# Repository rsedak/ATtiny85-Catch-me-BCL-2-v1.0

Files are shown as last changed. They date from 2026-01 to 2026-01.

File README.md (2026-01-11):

[Croatian version](README_HR-HR.md).

Introduction
============
My friend Zvonimir Lapov asked me if I could design THT PCB which would be used in primary school student education.
Purpose of 'Catch me BCL-2' module is student education. It shows advantages of charlieplexing with seven BI-color LEDs.
This version is designed for the case when the BI-color LED has a brighter LED on pin 3.
There are many variations of bi-color LEDs on the market, so you will need to define the resistors yourself.

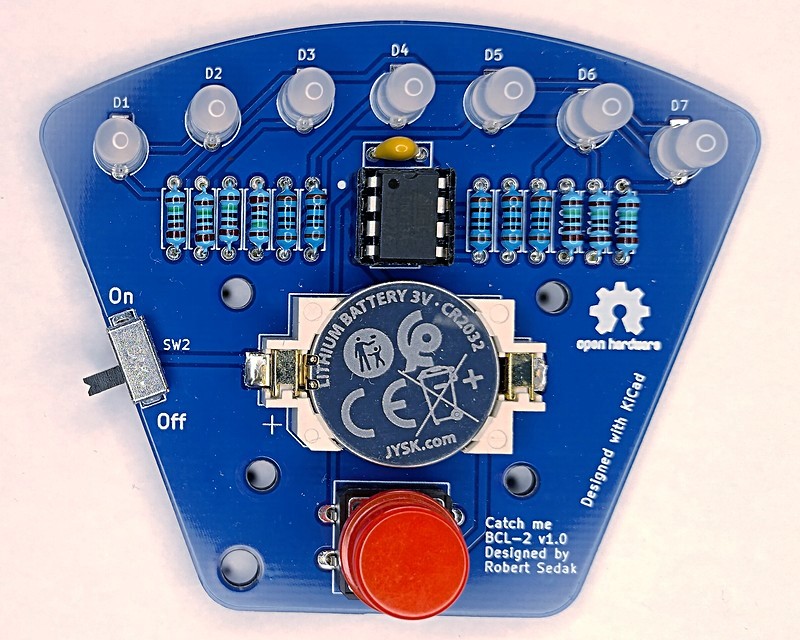
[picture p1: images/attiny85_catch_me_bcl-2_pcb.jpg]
PCB front Catch me BCL-2 educational module

Photo by Robert Sedak

Warning:
------------
In order for the program to be fully executed, the RESET pin on the ATtiny must be declared as an input/output pin. This is achieved by activating the FUSE bit called RSTDISBL. If we want to reprogram the ATtiny afterwards, we must turn off the FUSE bit called RSTDISBL using the high-voltage (12V) programming technique.
The procedure for programming the FUSE bits and the high-voltage programming technique can be found in professional literature. Use your newly acquired knowledge only when you fully understand what you have to do. Otherwise, you may damage the microcontroller.

Contributor
------------
- Robert Sedak — features, programming, schematic design, CAD design, case for PCB
- Zvonimir Lapov - idea

Application
-----------
Robert Sedak made a video with example programmed in Arduino IDE with ATtiny85 support:

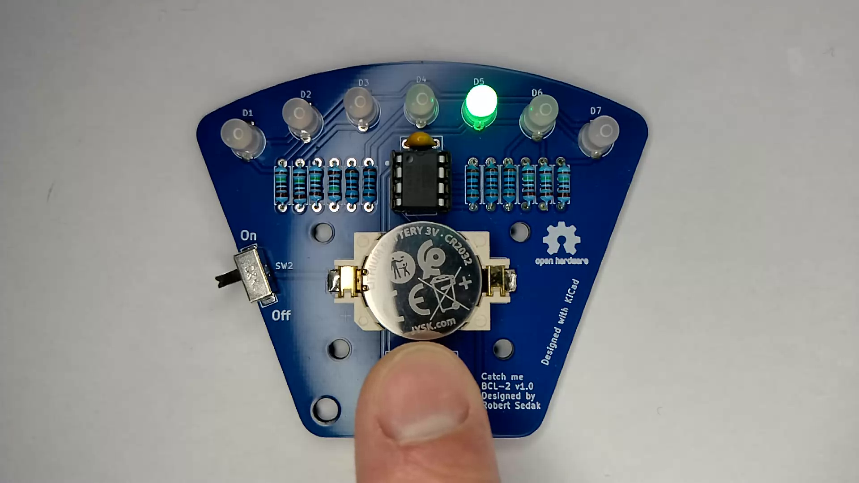
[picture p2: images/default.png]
PCB application (https://youtu.be/r-Ip-7PmgAQ "Catch me BCL-2 educational module example")

Photo by Robert Sedak

You can download example for Arduino IDE from [here](examples/).

Bill Of Materials
-----------------
- 1 ea., PCB
- 5 ea., 100 ohm 1/4W 1% Resistor (R1, R2, R3, R4, R5)
- 7 ea., 1.5K ohm 1/4W 1% Resistor (R6, R7, R8, R9, R10, R11, R12)
- 7 ea., BI-color LED 5mm (D1, D2, D3, D4, D5, D6, D7) with common cathode
- 4 ea., 6x6x4.3mm SPST Momentary push switch (SW1)
- 1 ea., SDPT 1P2T slide switch (SW2)
- 1 ea., 100nF 50V Monolithic Ceramic Capacitor
- 1 ea., 8-Pin DIL IC Socket
- 1 ea., ATtiny85 or ATtiny13A
- 1 ea., battery holder Keystone 1060
- 1 ea., battery 2032

Design Files
------------
This project is designed using Open Source [KiCad](http://kicad.org/). Design files are located in the [design_files](design_files/) folder.  You can see the [schematic](images/attiny85_catch_me_bcl-2_schematic.pdf).

Gerber files
------------
You can download gerber files from [here](gerber/attiny85_catch_me_bcl-2.zip).

Firmware
--------
This project can be programmed using the Open Source [Arduino](https://www.arduino.cc/).
[ATTinyCore by Spence Konde](https://github.com/SpenceKonde/ATTinyCore) was used to program ATtiny85 in Arduino IDE
[MicroCore by MCUdude](https://github.com/MCUdude/MicroCore) was used to program ATtiny13 in Arduino IDE.
Arduino examples for Arduino IDE are located in [examples](examples/) folder.

Case
-------
Robert Sedak created case for PCB. You can download STL and FCStd file from [case](case/) folder.
This case was designed using Open Spource [FreeCAD](https://www.freecad.org/).

**Bill Of Connecting Materials**
- 4 ea., M3 nuts
- 4 ea., M3x5mm + 4mm  Male to Female plastic Hex Spacer
- 4 ea., M3x5mm plastic screw

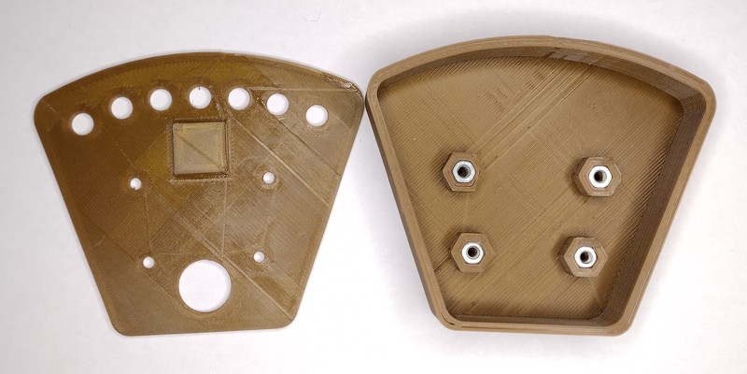
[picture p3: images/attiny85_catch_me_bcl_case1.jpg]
Shield case Catch me educational module

Photo by Robert Sedak

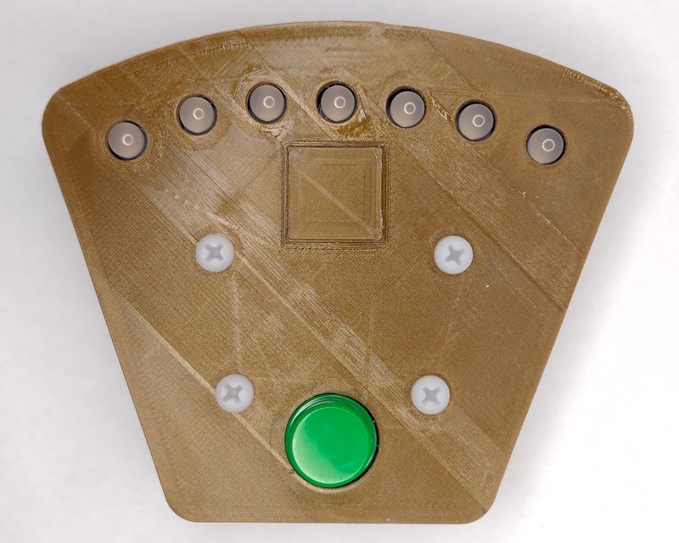
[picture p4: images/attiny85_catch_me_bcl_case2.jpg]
Shield case Catch me educational module

Photo by Robert Sedak

License
-------
[Attribution-ShareAlike 4.0 International (CC BY-SA 4.0)](https://creativecommons.org/licenses/by-sa/4.0/)

You are free to:
- Share — copy and redistribute the material in any medium or format
- Adapt — remix, transform, and build upon the material

This license is acceptable for Free Cultural Works.
- The licensor cannot revoke these freedoms as long as you follow the license terms.

Under the following terms:
- Attribution — You must give appropriate credit, provide a link to the license, and indicate if changes were made. You may do so in any reasonable manner, but not in any way that suggests the licensor endorses you or your use.
- ShareAlike — If you remix, transform, or build upon the material, you must distribute your contributions under the same license as the original.

No additional restrictions — You may not apply legal terms or technological measures that legally restrict others from doing anything the license permits.

Reference Designs ARE PROVIDED "AS IS" AND "WITH ALL FAULTS". Authors DISCLAIMS ALL OTHER WARRANTIES, EXPRESS OR IMPLIED, REGARDING PRODUCTS, INCLUDING BUT NOT LIMITED TO, ANY IMPLIED WARRANTIES OF MERCHANTABILITY OR FITNESS FOR A PARTICULAR PURPOSE.
Authors may make changes to specifications and product descriptions at any time, without notice. The Customer must notrely on the absence or characteristics of any features or instructions marked "reserved" or "undefined."
Authors reservesthese for future definition and shall have no responsibility whatsoever for conflicts or incompatibilities arising from future changes to them. The product information on the Web Site or Materials is subject to change without notice. Do not finalize a design with this info.

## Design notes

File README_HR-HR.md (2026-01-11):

[Engleska verzija](README.md).

Uvod
============
Prijatelj Zvonimir Lapov me upitao bi li mogao dizajnirati pločicu u THT tehnologiji za potrebe edukacije učenika osnovnih škola.
Svrha edukacijskog modula "Uhvati me BCL-2" je edukacija učenika. Pokazuje prednosti spajanja sedam dvobojnih svjetlećih dioda u spoj charlieplexing (multipleksiranje sa tri stanja).
Ova verzija je dizajnirana za slučaj kada dvobojna svjetleću dioda ima svjetliju diodu na pinu 3.
Na tržištu postoji mnogo varijacija dvobojnih svjetlećih dioda, pa ćete morati sami definirati otpornike.

PCB application Edukacijski modul Uhvati me BCL-2
Fotografirao Robert Sedak

Pozor:
------------
Kako bi se program u cijelosti mogao izvršiti, na ATtiny pin RESET moramo deklarirati kao ulazno/izlazni pin. To se postiže aktiviranjem FUSE bita s nazivom RSTDISBL. Ukoliko nakon toga želimo ponovno programirati ATtiny, moramo isključiti FUSE bit s nazivom RSTDISBL pomoću tehnike programiranja pomoću visokog napona (12V).
Postupak programiranja FUSE bitova i tehniku programiranja pomoću visokog napona potražite u stručnoj literaturi. Novostećena znanja koristite tek kada potpuno razumijete što morate napraviti. U suprotnom možete oštetiti mikroupravljač.

Autor
------------
- Robert Sedak — svojstva, programiranje, dizajn el. scheme, CAD dizajn, kučište
- Zvonimir Lapov - ideja

Programiranje
-----------
Robert Sedak je snimio video s primjerom programiranim u Arduino IDE s podrškom za ATtiny85:
PCB application (https://youtu.be/r-Ip-7PmgAQ "Edukacijski modul Uhvati me BCL-2 - primjer programiranja")
Fotografirao Robert Sedak

Primjere za Arduino IDE možete preuzeti [ovdje](examples/).

Popis komponenti
-----------------
- 1 kom, PCB
- 5 kom, 100 ohm 1/4W 1% otpornik (R1, R2, R3, R4, R5)
- 7 kom, 1.5K ohm 1/4W 1% otpornik (R6, R7, R8, R9, R10, R11, R12)
- 7 kom, dvobojna LED 5mm (D1, D2, D3, D4, D5, D6, D7) za zajedničkom katodom
- 1 kom, 6x6x4.3mm SPST tipkalo (SW1)
- 1 kom, SDPT 1P2T pomični prekidač (SW2)
- 1 kom, 100nF 50V keramički kondenzator
- 1 kom, 8-Pin DIL IC podnožje
- 1 kom, ATtiny85 ili ATtiny13A
- 1 kom, kučište za bateriju Keystone 1060
- 1 kom, baterija 2032

Datoteke s dizajnom
------------
Ovaj semafor je dizajniran pomoću programa [KiCad](http://kicad.org/). Datoteke se nalaze u mapi [design_files](design_files/). Elekroničku schemu možete pogledati [ovdje](images/attiny85_catch_me_bcl-2_schematic.pdf).

Gerber datoteke
------------
Gerber datoteke možete preuzeti [ovdje](gerber/attiny85_catch_me_bcl-2.zip).

Firmware
--------
Ovo učilo može biti progrmairano pomoću [Arduino IDE](https://www.arduino.cc/).
[ATTinyCore by Spence Konde](https://github.com/SpenceKonde/ATTinyCore) je korišten za programiranje ATtiny85 u Arduino IDE.
[MicroCore by MCUdude](https://github.com/MCUdude/MicroCore) je korišten za programiranje ATtiny13A u Arduino IDE.
Primjeri za Arduino IDE se nalaze u mapi [examples](examples/).

Kučište
-------
Robert Sedak je dizajnirao kučište za pločicu. Možete preuzeti datoteke u STL i FCStd obliku iz mape [case](case/).
Ovo kučište je dizajnirano pomoću programa [FreeCAD](https://www.freecad.org/).

**Popis spojnih materijala**
- 4 kom, matica M3
- 4 kom, M3x5mm + 4mm plastični odstojnik sa unutarnjim i vanjskim navojem
- 4 kom, M3x5mm plastični vijak

PCB kučište Catch me educational module
Fotografirao Robert Sedak

PCB kučište Catch me educational module
Fotografirao Robert Sedak

Licenca
-------
[Imenovanje-Dijeli pod istim uvjetima 4.0 međunarodna (CC BY-SA 4.0)](https://creativecommons.org/licenses/by-sa/4.0/deed.hr)

Slobodno možete:
- Dijelite dalje — možete umnažati i redistribuirati materijal u bilo kojem mediju ili formatu
-  Stvarajte prerade — možete remiksirati, mijenjati i prerađivati djelo u bilo koju svrhu, pa i komercijalnu

Davatelj licence ne može opozvati slobode korištenja koje Vam je ponudio dokle god se pridržavate uvjeta licence.

Pod sljedećim uvjetima:
- Imenovanje — Morate adekvatno navesti autora, uvrstiti link na licencu i naznačiti eventualne izmjene. Možete to učiniti na bilo koji razuman način, ali ne smijete sugerirati da davatelj licence izravno podupire Vas ili Vaše korištenje djela.
- Dijeli pod istim uvjetima — Ako remiksirate, mijenjate ili prerađujete materijal, Vaše prerade morate distribuirati pod istom licencom pod kojom je bio izvornik.

Bez daljnjih ograničenja — Ne smijete dodavati pravne uvjete ili tehnološke mjere zaštite koji će druge pravno ograničiti da čine ono što im licenca dopušta.

Odricanje od odgovornosti
-------------------------
NAPOMENA - Dizajn je objavljen u dobroj namjeri i "takav kakav je" ("AS IS"), te sa mogućim greškama. Autor je kreirao učilo, slike, video i programski kod. Autoru je radilo i uspjelo raditi na način kako je opisano, što ne znaći da će raditi i Vama. Ne odgovaram ni za kakve posljedice koje mogu nastati prilikom korištenja učila, uputa ili programskog koda. Odričem se sve odgovorosti i jamstva- sami ste odgovorni za ono što radite i sami ste odgovorni što ste pristali pratiti i koristiti naše upute i informacije.

Autor može mijenjati specifikacije i opise proizvoda u bilo kojem trenutku, bez prethodne obavijesti. Korisnik se ne smije osloniti na odsutnost ili karakteristike bilo kojih značajki ili uputa označenih kao "rezervirano" ili "nedefinirano".
Autor zadržava pravo budućih izmjena definicija i neće snositi nikakvu odgovornost za sukobe ili nekompatibilnosti koje proizlaze iz budućih promjena. Podaci o proizvodu na web stranici ili materijalima podložni su promjenama bez prethodne obavijesti. Nemojte finalizirati dizajn s ovim podacima.

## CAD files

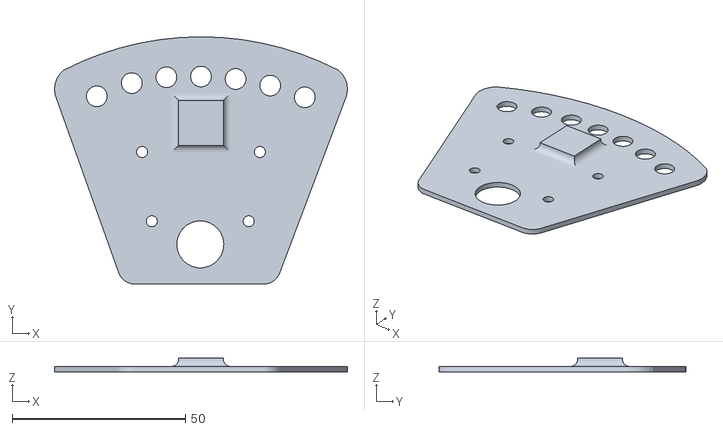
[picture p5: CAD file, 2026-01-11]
case/catch_me_bcl_case-cover.stl
84.7 x 71.5 x 4.00

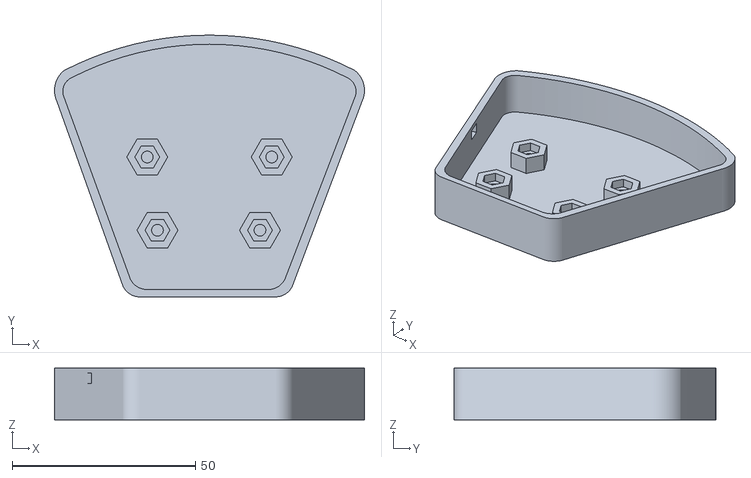
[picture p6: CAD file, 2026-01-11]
case/catch_me_bcl_case-box.stl
84.7 x 71.5 x 14.2

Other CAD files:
case/catch_me_bcl_case.FCStd

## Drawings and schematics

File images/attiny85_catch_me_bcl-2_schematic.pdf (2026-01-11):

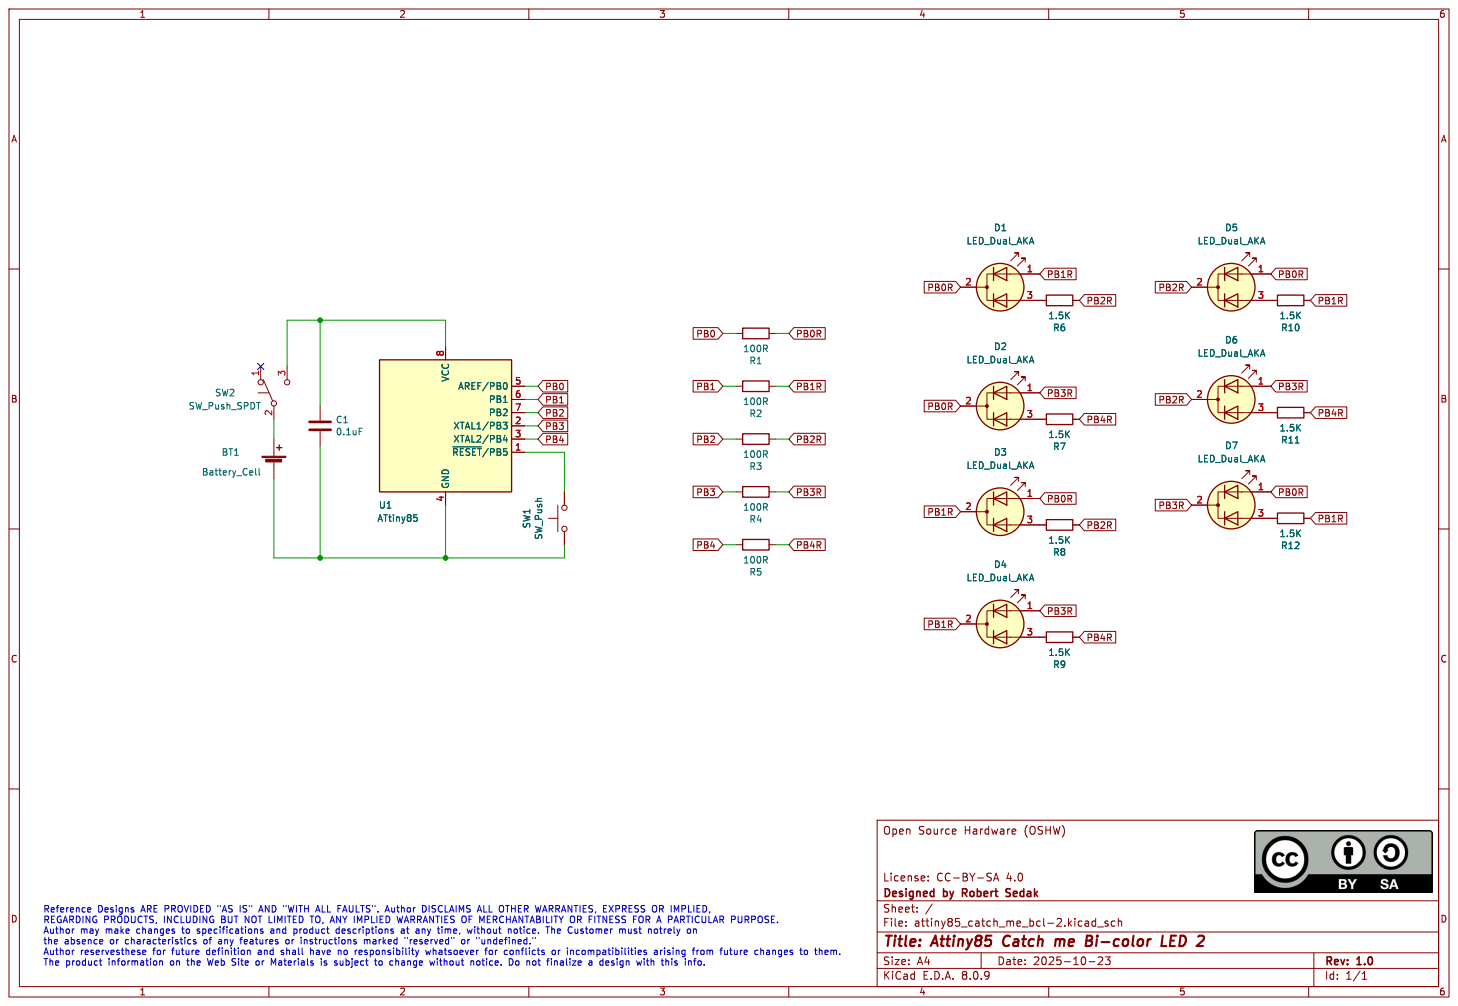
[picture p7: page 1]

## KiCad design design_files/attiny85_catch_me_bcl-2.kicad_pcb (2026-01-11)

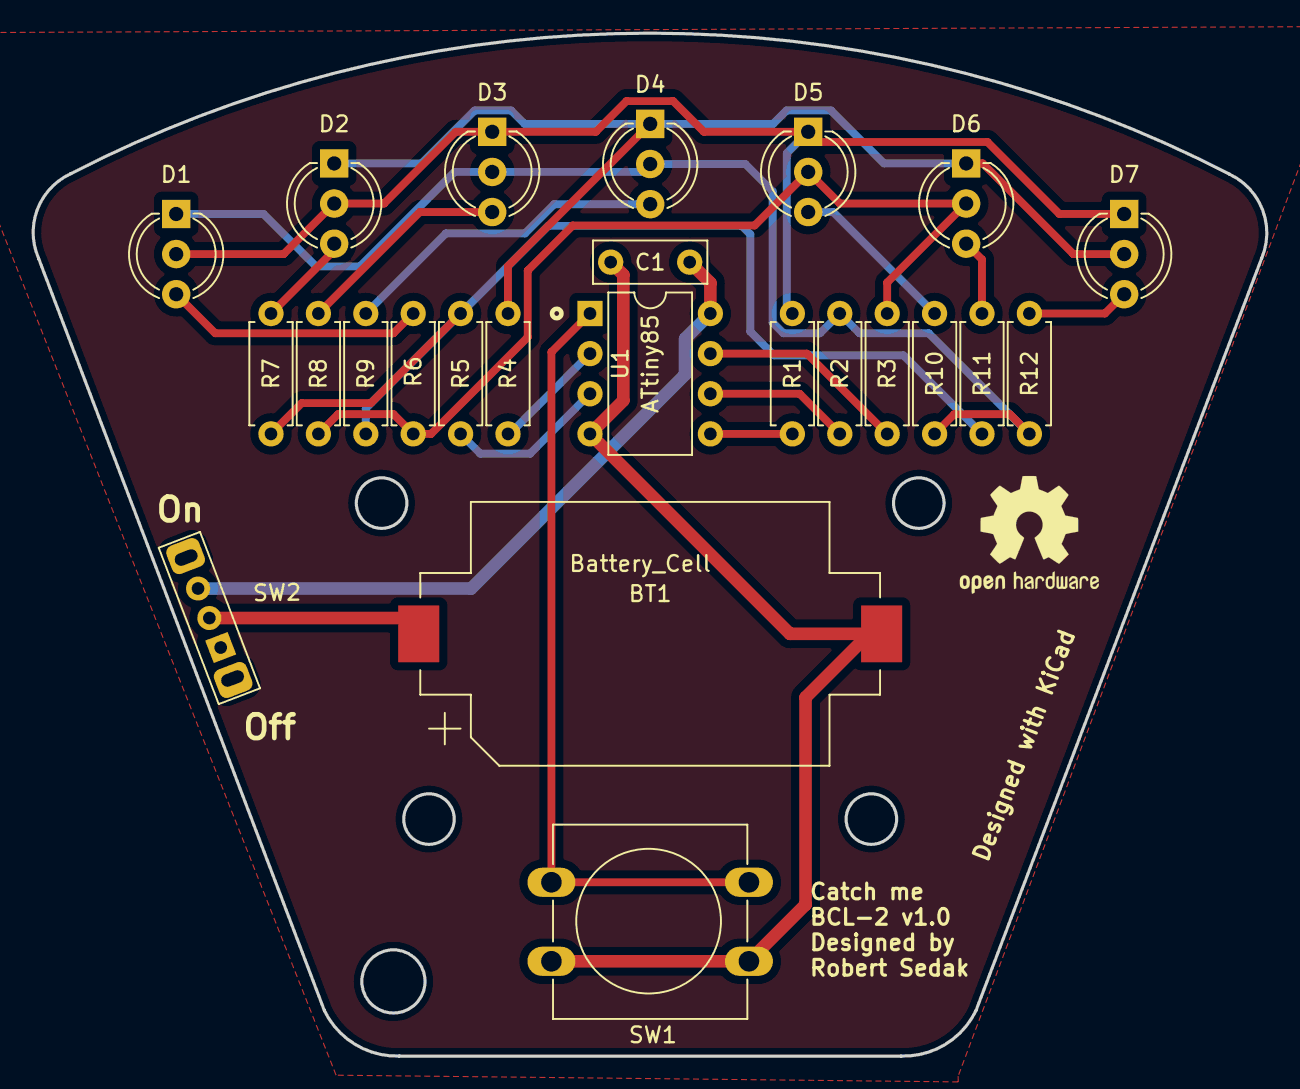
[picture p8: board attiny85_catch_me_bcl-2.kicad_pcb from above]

Board: 2 copper layers, 78.1 x 64.7 mm, 24 parts (0 on the bottom side), 21 nets.

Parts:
BT1: Battery_Cell; BatteryHolder_Keystone_1060_1x2032
C1: 0.1uF; C_Rect_L7.0mm_W2.5mm_P5.00mm
D1, D2, D3, D4, D5, D6, D7: LED_Dual_AKA; LED_D5.0mm-3
R1, R2, R3, R4, R5, R6, R7, R8, R9, R10, R11, R12: 120R; R_Axial_DIN0207_L6.3mm_D2.5mm_P7.62mm_Horizontal
SW1: SW_Push; SW_PUSH-12mm
SW2: SW_Push_SPDT; SW_Slide_SPDT_1P2TC_right_angle
U1: ATtiny85; DIP-8_W7.62mm

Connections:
unnamed: BT1.1 (+), SW2.2 (B)
unnamed: BT1.2 (-), C1.2, SW1.1, U1.4 (GND)
unnamed: C1.1, SW2.3 (C), U1.8 (VCC)
unnamed: D1.3 (A2), R6.1
unnamed: D2.3 (A2), R7.1
unnamed: D3.3 (A2), R8.1
unnamed: D4.3 (A2), R9.1
unnamed: D5.3 (A2), R10.1
unnamed: D6.3 (A2), R11.1
unnamed: D7.3 (A2), R12.1
unnamed: SW1.2, U1.1 (~RESET/PB5)
PB0: R1.1, U1.5 (AREF/PB0)
PB0R: D1.2 (K), D2.2 (K), D3.1 (A1), D5.1 (A1), D7.1 (A1), R1.2
PB1: R2.1, U1.6 (PB1)
PB1R: D1.1 (A1), D3.2 (K), D4.2 (K), R2.2, R10.2, R12.2
PB2: R3.1, U1.7 (PB2)
PB2R: D5.2 (K), D6.2 (K), R3.2, R6.2, R8.2
PB3: R4.1, U1.2 (XTAL1/PB3)
PB3R: D2.1 (A1), D4.1 (A1), D6.1 (A1), D7.2 (K), R4.2
PB4: R5.1, U1.3 (XTAL2/PB4)
PB4R: R5.2, R7.2, R9.2, R11.2

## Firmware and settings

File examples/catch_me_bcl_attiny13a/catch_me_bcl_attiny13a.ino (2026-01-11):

/*
 * Catch me bi-color for ATtiny13A
 *  
 * Created 2025 by Robert Sedak
 * 
 * This example code is in the public domain.
 *  
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
 * Charlieplexing: D0, D1, D2
 * Green LED: D3
 * Push-button: D4
 * 
 * Press button when GREEN LED is turned on. 
 * If the push-button is pressed when GREEN LED is turned on, the duration for which the 
 * LED remains lit is reduced by approximately 12%.
 * If you press push-button when RED LED is turned on:
 *   - The LED light duration is configured to the initial level.
 *   - LED0 blinks a number of times equal to the tens digit of the current level number.
 *   - LED1 blinks a number of times equal to the units digit of the current level number.
 * 
 * Game levels: 21
 * 
 * 
 * Programmed with Arduino IDE and 
 * Arduino core for attiny13 - https://mcudude.github.io/MicroCore/package_MCUdude_MicroCore_index.json
 *  
 * Tested on ATtiny13A running at 1.2MHz.
 * Programing parameters with Arduino IDE:
 * BOD: disabled
 * Clock: 1.2MHz internal osc.
 * Bootloader: No bootloader
 * 
 * 
 */

const byte OCR0A_initial_value = 4;      // Inital value for OCR0A to trigger interrupt every  3.41ms
const byte OCR0B_initial_value = 38;     // Inital value for OCR0B to trigger interrupt every 32.43ms


/* -------------------------------------------------------------------------------------
*  The following definitions clarify the operation of Charlieplexed LEDs, 
*  focusing on the flow of current between pairs of ports.
    - 3:2 Bits: These bits determine which port should be set to a high state (active).
    - 1:0 Bits: These bits determine which port should be set to a low state (inactive).
   -------------------------------------------------------------------------------------
*/
const byte CharlieLED[7] = {
  0b01000100,                            // LED 1
  0b10001100,                            // LED 2
  0b01000001,                            // LED 3
  0b10001101,                            // LED 4
  0b00100010,                            // LED 5  
  0b10001110,                            // LED 6
  0b00100011                             // LED 7
};


/* ------------------------------------------------------------------
*  Specifies the sequence of green LEDs that will be turned on.
*  ------------------------------------------------------------------
*/
const byte greenLedSequence[7] = {0, 4, 1, 5, 2, 6, 3};


/* ------------------------------------------------------------------
*  Defines the various playing levels along with the corresponding 
*  durations for which the LED lights will remain turned on.
*  ------------------------------------------------------------------
*/
const byte levels = 21;
const byte duration[levels] = {
  139, 122, 107, 94, 83, 73, 64,
  56, 49, 43, 38, 34, 30, 27,
  24, 21, 19, 17, 15, 13, 11
};


/* --------------------------------------------------------------------
*   Lists the variables necessary for the program to function correctly.
*  --------------------------------------------------------------------
*/
volatile uint16_t currentticks = 0;
volatile uint16_t lastticks = 0;
volatile bool previousSwitchReading = 1;
volatile bool buttonIsPressed = 0;
volatile bool buttonWasPressed = 0;
volatile byte currentLED = 0;
volatile byte LEDstep = 1;
volatile byte level = 0;
volatile byte greenLED = 3;
volatile byte greenLedPosition = 0;


void setup() {
  pinMode(0, INPUT);      // set pin 0 to 
  digitalWrite(0, LOW);   // Hi-Z state
  pinMode(1, INPUT);      // set pin 1 to 
  digitalWrite(1, LOW);   // Hi-Z state
  pinMode(2, INPUT);      // set pin 2 to 
  digitalWrite(2, LOW);   // Hi-Z state
  pinMode(3, INPUT);      // set pin 3 to 
  digitalWrite(3, LOW);   // Hi-Z state
  pinMode(4, INPUT);      // set pin 4 to 
  digitalWrite(4, LOW);   // Hi-Z state
  pinMode(5, INPUT_PULLUP);
  
  cli();                                   // Disable global interrupts
  TCCR0B |= (1<<CS02) | (1<<CS00);         // Start timer prescaler to 1024
  TIMSK0 |= (1 << OCIE0A) | (1 << OCIE0B); // Enable Counter Output Compare Match A and B Interrupt
  OCR0A = OCR0A_initial_value;             // Set OCR0A
  OCR0B = OCR0B_initial_value;             // Set OCR0B
  TCNT0 = 0;                               // Reset Timer/Counter Register
  sei();                                   // Enable global interrupts
} // end of function setup()


/* ------------------------------------------------------------------
*  An interrupt function that counts ticks, 
*  serving as a substitute for the traditional delay function.
*  ------------------------------------------------------------------
*/
ISR(TIM0_COMPA_vect)
{
  OCR0A += OCR0A_initial_value;            // set counter for the next trigger
  ++currentticks;                          // increase counter
} // end of function ISR()


/* ------------------------------------------------------------------
*  An interrupt function that detects when a push-button is pressed, 
*  incorporating a debounce algorithm to ensure reliable operation.
*  ------------------------------------------------------------------
*/
ISR(TIM0_COMPB_vect)
{
  OCR0B += OCR0B_initial_value;       // set counter for the next trigger
  bool currentSwitchReading = digitalRead(5);
  if (currentSwitchReading == previousSwitchReading)
  {
    if (!currentSwitchReading){
      buttonIsPressed = 1;
    } else {
      buttonIsPressed = 0;
    }
  }
  previousSwitchReading = currentSwitchReading;
} // end of function ISR()


/* ------------------------------------------------------------------
*  Substitute for the traditional delay function.
*  ------------------------------------------------------------------
*/
void delayLED(int interval) {
  currentticks = 0;               // I want 8 bit numbers comparation
  lastticks = currentticks;
  while (interval > currentticks - lastticks) {};
} // end of function delayLED()


/* ------------------------------------------------------------------
*  This function blinks #thisLED a specified number of #times. 
*  Its purpose is to provide visual confirmation that the push-button
*  has been pressed and to inform the player of the total number of 
*  times the button was activated while the green LED was turned on.
*  ------------------------------------------------------------------
*/
void blinkLED(byte thisLED, byte times) {
  for (int i = 1; i <= times; i++) {
    LEDON(thisLED);
    delayLED(100);
    LEDOFF(thisLED);
    delayLED(100);
  }
} // end of function blinkLED()


void loop() {
  LEDON(currentLED);
  currentticks = 0;          // I want 8 bit numbers comparation
  lastticks = currentticks;
  switch(currentLED){
    case 6:                  // let's switch directioN from highest LED to lowest
      LEDstep = -1;
      break;
    case 0:                  // let's switch direction from lowest LED to highest
      LEDstep = 1;
      break;
    default:                 // do nothing, everything is fine
      break;
  }
  while (duration[level] > currentticks - lastticks) {
    if (buttonIsPressed) {
      buttonWasPressed = 1;
      break;
    }
  }
  while (buttonIsPressed == 1) {};

  LEDOFF(currentLED);
  
  if (buttonWasPressed) {     // when push-button is presses, fun time 
    delayLED(100);            // wait so playe see LED is not lit
    blinkLED(currentLED, 2);  // let current LED blink two times
    if (currentLED == greenLED && level < levels) {  // button had been pusshed when green LED was turned on
      level++;                                       // move to the next game level
      greenLED = greenLedSequence[greenLedPosition]; // change green LED position
      greenLedPosition++;
      if (greenLedPosition == 7) {
        greenLedPosition = 0;
      }
   } else {                  // show how many times player pushed button when green LED was turned on
      blinkLED(0, level/10);  // show tens
      blinkLED(1, level%10);  // show units
      level = 0;              // start over
    }
    buttonWasPressed = 0;
  }

  currentLED += LEDstep;        // change the LED to be turned on
} // end of function loop()


/* --------------------------
*  Turn the LED #thisLED off.
* ---------------------------
*/
void LEDOFF(byte thisLED) {
  // turn off
  byte pin1 = (CharlieLED[thisLED] & 0b00011100) >> 2;  // find pin1 for red
  if(thisLED == greenLED) {
    pin1 = (CharlieLED[thisLED] & 0b11100000) >> 5;  // find pin1 for green
  }
  byte pin2 = CharlieLED[thisLED] & 0b00000011;         // find pin2
  pinMode(pin1 , INPUT);    // set pin1 to
  digitalWrite(pin1, LOW);  // Hi-Z state
  pinMode(pin2, INPUT);     // set pin2 to
  digitalWrite(pin2, LOW);  // Hi-Z state
} // end of function LEDOFF()


/* -------------------------
*  Turn the LED #thisLED on.
*  -------------------------
*/
void LEDON(byte thisLED) {
  // turn on the one that's in focus
  byte pin1 = (CharlieLED[thisLED] & 0b00011100) >> 2;  // find pin1 for red
  if(thisLED == greenLED) {
    pin1 = (CharlieLED[thisLED] & 0b11100000) >> 5;  // find pin1 for green
  }
  byte pin2 = CharlieLED[thisLED] & 0b00000011;         // find pin2
  pinMode(pin1, OUTPUT);
  digitalWrite(pin1, HIGH);
  pinMode(pin2, OUTPUT);
  digitalWrite(pin2, LOW);
} // end of function LEDON()

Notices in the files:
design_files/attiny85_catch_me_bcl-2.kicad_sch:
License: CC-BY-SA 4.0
